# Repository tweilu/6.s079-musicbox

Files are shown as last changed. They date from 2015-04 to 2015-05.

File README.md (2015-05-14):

# 6.s079-musicbox
Final project for 6.S079 Computational Fabrication.

Final Report: Documentation/6.S079FinalReport.pdf

Web application: https://tweilu.scripts.mit.edu/musicbox/

Directory Structure

- CAD/ contains the CAD files for the static music box parts
- Code/
  - Cylinder/ contains the OpenSCAD and OpenJsCad scripts for cylinder generation and some example cylinders
  - Comb/ contains the original Python script and the ported OpenJsCad script for comb generation and some example combs
  - MIDI-Parser/ contains the standalone MIDI parser code
- Documentation/ contains all the reports and presentations from class
- Examples/ contains example MIDI files
- webapp/ contains the source code for the web application, which combines the MIDI parser with the cylinder and comb scripts

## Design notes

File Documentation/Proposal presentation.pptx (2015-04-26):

## Music boxes from MIDI

Wei-Wei Lu, Trevor Walker

## Problem and Motivation

- Inspired by project idea shown in class
  - Custom music boxes traditionally costly
- Manual note and scale input is tedious
  - MIDI encodes all necessary information
- Plastic comb sounds bad
  - Computational fabrication techniques work with other materials too

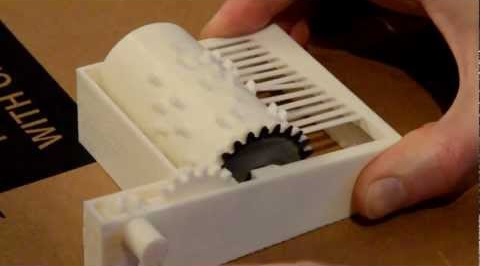
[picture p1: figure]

## Background and Tools

- Major music box parts and their functions
  - Cylinder (notes/timing)
  - Comb (scale)
  - Clockwork mechanism (tempo)
- OpenSCAD
  - Parametric description of part → printable STL
  - Applying skills learned from assignment 2

## Technical Method: Generation

- Front end: JavaScript web app
  - User access is easy
  - No external libraries or installation required
- Back end: OpenJSCAD
  - JavaScript wrapper for OpenSCAD
  - JS code determines low-level parameters, then passes them to SCAD routine
- User parameters
  - Which MIDI track to use
  - Which portion of song to encode on cylinder

## Technical Method: Fabrication

- Cylinder and mechanism: 3D printed ABS/PLA
  - Feasibility already shown
  - Gears and mechanisms are common
- Comb: Laser cut stainless steel
  - Sounds much better than plastic
  - Very thin metal is possible to laser cut
  - Dimensions can be matched to known acoustic properties of alloy

## Expected results

- Web app for generating printable files
  - Only necessary parameters exposed
  - Produces downloadable STL/OBJ for printing and SVG/DXF for laser cutting
- Functional music boxes
  - Demonstrated during final presentation

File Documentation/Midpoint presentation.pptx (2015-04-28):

## Midpoint: MIDI music boxes

Wei-Wei Lu, Trevor Walker

## Project recap

- 3D printing custom music boxes
- Interactive design based on MIDI
- Improves on existing solutions
  - Easier to design
  - Better sound


## Project components

- 3D-printable music box, without cylinder
- MIDI parser producing OpenSCAD files for cylinder
- Python script generating comb to correspond with cylinder
- Web app for interactive generation of comb and cylinder from MIDI

## Progress so far

- Complete

- Base music box
- MIDI → cylinder conversion
- Automatic comb generation

- In progress

- Web interface

## Example cylinder

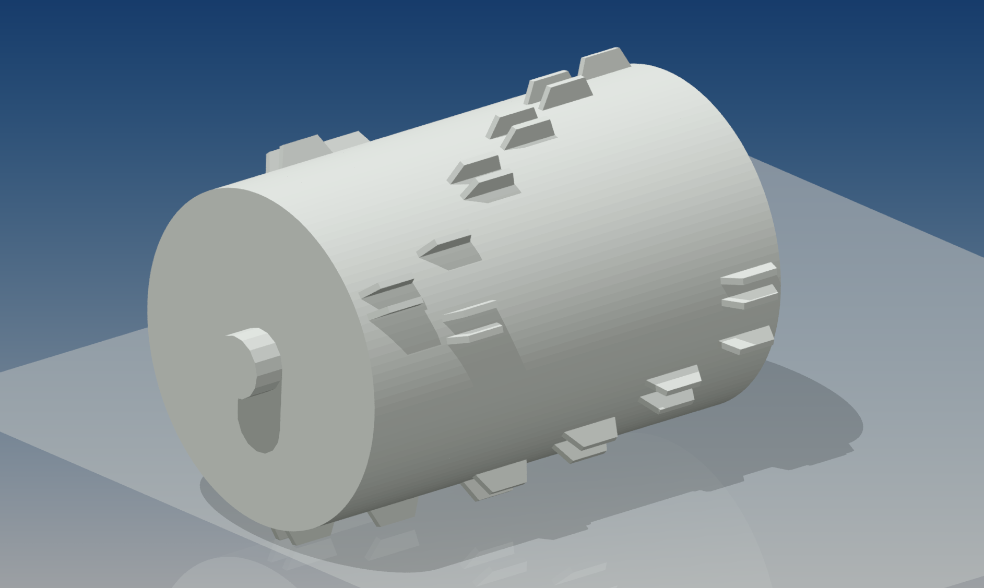
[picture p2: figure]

## Music box frame

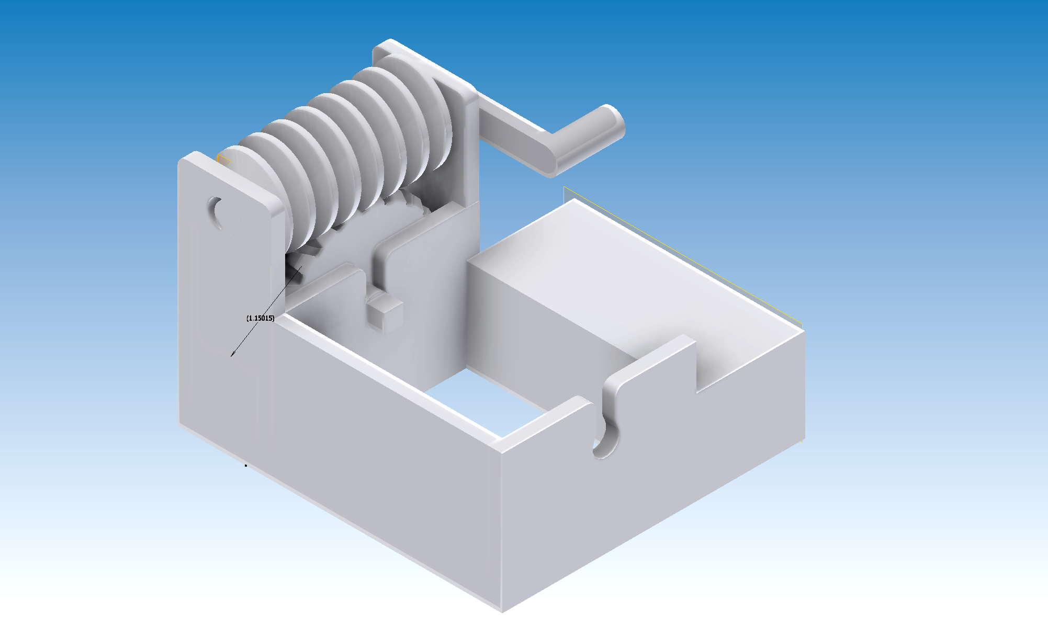
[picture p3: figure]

## Example comb

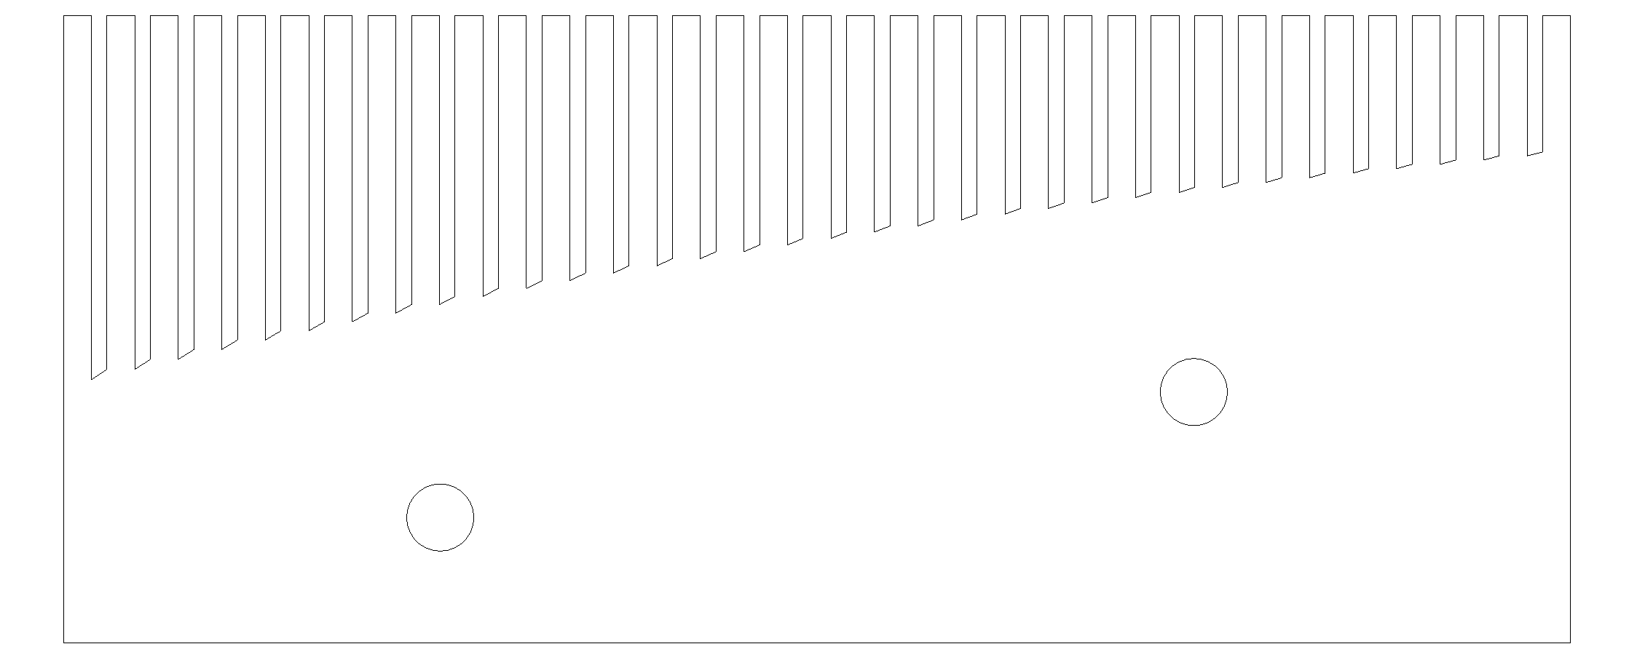
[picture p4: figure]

## What’s left

- Finish web app
- Prototype
  - Test whether fabricated design meets expectations
- Iterate
  - Improve anything not up to spec

## Questions?

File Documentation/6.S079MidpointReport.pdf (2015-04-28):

Music Box Generation from MIDIs 6.S079 Midpoint Project Report Trevor Walker and Tiffany Lu

Motivation

The problem we are tackling with our final project is allowing users to generate custom music boxes by simply uploading a MIDI music file containing the melody. The key goals in this task are to decrease the cost to the user of creating a custom music box and to make it easier to generate boxes by allowing a user to upload the desired song instead of having to manually input each note and the rhythms while still maintaining good sound quality. The custom 3D-printed music box was suggested in class; however, inputting the song for the music box is very clunky, and the fully 3D-printed box does not sound very good due to the plastic’s thin sound, so we plan to integrate a steel comb in order to make the custom boxes sound like traditional music boxes.

Technical Approach

In order to generate the custom music boxes, we will build a node.js web application that allows the user to upload a MIDI file and will output the .STL and .DXF for 3D printing and laser cutting. There are four main components to this: the JavaScript MIDI parser, the cylinder generation, the comb generation, and the box generation. The web application will provide an interface that allows users to upload a file and then subsequently view and download the resulting files.

MIDI Parser
The role of the JavaScript MIDI parser is to extract the relevant note and timing data from the MIDI file to pass to both the cylinder and comb modules. The web application provides an input field for the user to upload a file, and once chosen, it is read as a binary string and fed into a JavaScript MIDI parser called jasmid (https://github.com/gasman/jasmid). The parser surfaces a “header” portion of the MIDI file, which contains the MIDI format, number of tracks, and the timing interval, as well as a “tracks” portion of the file, which contains the actual note data. The “tracks” property contains a list of events for each track. We use only the MIDI “note on” event to signify when a note should be played, ignoring the “note off” event because a music box cannot sustain notes.

To generate the comb, we require all unique notes that are played through the whole song, so we iterate through the “note on” events to gather the unique MIDI note numbers. To generate the cylinder, we require [combtooth number, timing] pairs. We use the list of unique notes to get the combpin numbers, and to get the timing, each event also has a deltatime property, which indicates the time between the current event and the last, so we build the [combtooth number, timing] pairs by accumulating those differences. These two arrays are passed on to their respective modules.

Comb
The comb component is a Python script that takes in the list of unique notes in the song in the MIDI note number format and outputs a .DXF file for laser cutting. The lengths of the teeth on the comb are calculated by taking the MIDI note numbers and converting them to frequency, and using the following equation to calculate the length:

L = √
0.162 f

a√d

Y

where a is thickness, f is frequency, Y is the Young’s modulus, d is density, and L is the length. For the stainless steel we intend to cut the comb out of, the constants are:
a = 0.36 in
d = 0.289 lbs/in

3
Y = 2.85 x 10

7 ksi

The output .DXF is created using the ezdxfPython library.

Cylinder
The cylinder component is an OpenJSCAD routine, which takes in the [combtooth, timing] pairs as described above and generates a 3D-printable cylinder (.STL) with pins in the corresponding locations. The spacing between the pins both along and around the cylinder is variable and depends on the length of the song and the number of unique notes the song contains.

We calculate the spacing of the pins around the cylinder using the length of the song and the circumference of the cylinder, and we calculate the spacing of the pins along the cylinder using the number of unique notes the song contains. To place the pins on the cylinder, we iterate through the array of pairs and calculate the angle offsets depending on the timing.

Music Box
The box component is designed statically as a CAD file, which provides slots to insert the cylinder and comb. The box uses a worm drive attached to a crank to turn the cylinder.

Progress & Current Results

Currently, each of the separate components as described above are implemented, but they have not yet been integrated with each other. The MIDI parser is currently a static HTML page that takes in a useruploaded file and outputs the relevant data to the console.

The comb Python script takes in a list of notes to put on the comb and outputs a .DXF file as seen below.

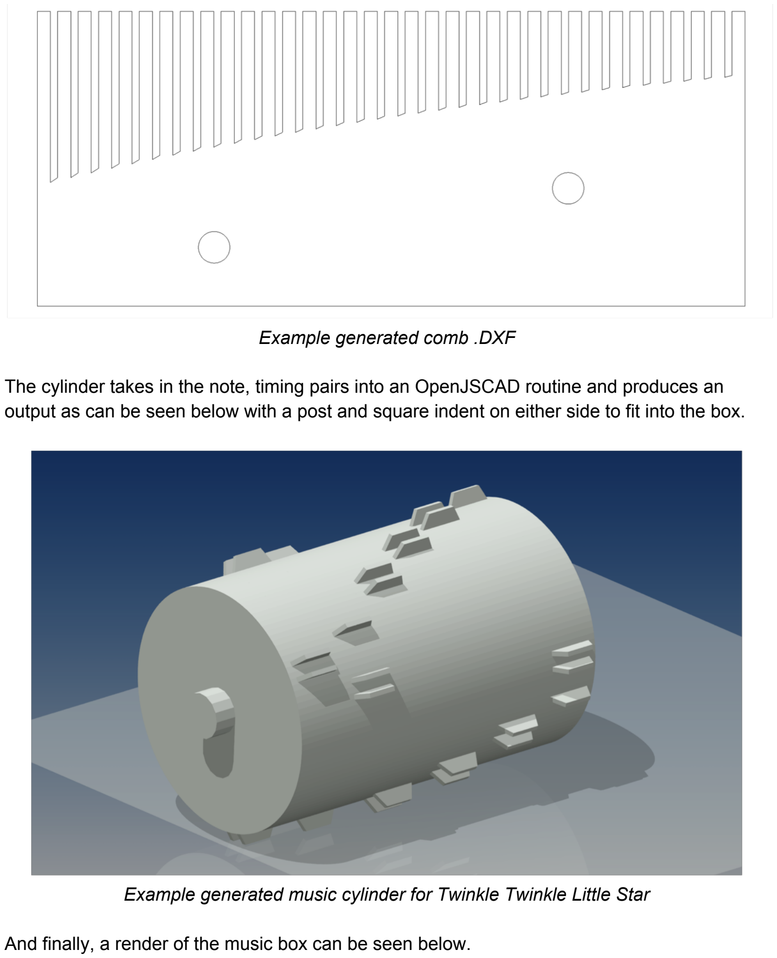
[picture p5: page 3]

Example generated comb .DXF

The cylinder takes in the note, timing pairs into an OpenJSCAD routine and produces an output as can be seen below with a post and square indent on either side to fit into the box.

Example generated music cylinder for Twinkle Twinkle Little Star

And finally, a render of the music box can be seen below.

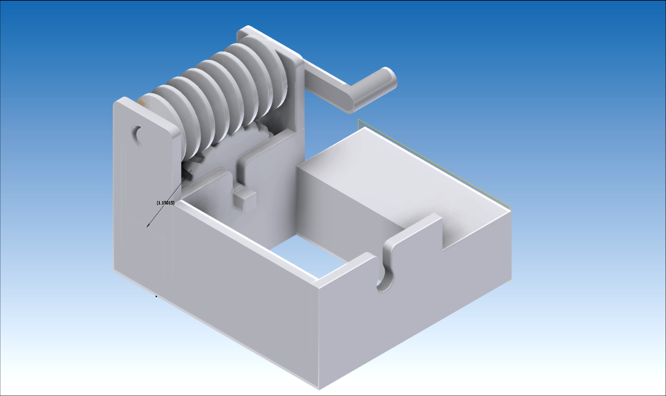
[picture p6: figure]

Music box render

Next Steps & Expected Results

The next steps for this project are to connect all of the four components together into the final web application. We also need to print and laser cut the generated objects to ensure they work together and make adjustments as needed. We plan to evaluate the laser cut comb by comparing the output frequencies with the desired ones, and we will compare the sound quality and overall function of the music box with both real and fully 3D printed ones.

We expect our final product to allow the user to upload a MIDI file and be able to download their corresponding .STL and .DXF files in the same interface. We also expect to have a few printed music boxes, generated by our system.

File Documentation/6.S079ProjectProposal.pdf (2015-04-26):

Music Box Generation from MIDIs 6.S079 Project Proposal
Trevor Walker and Tiffany Lu

Problem and Motivation
The problem we wish to tackle with our final project is allowing users to generate custom music boxes by simply uploading a MIDI music file containing the melody. Our overall goals are to decrease the cost to the user of creating a custom music box and to make it easier to generate boxes by allowing a user to upload the desired song instead of having to manually input each note and the rhythms while still maintaining good sound quality. The custom 3D-printed music box was suggested in class; however, the fully 3D-printed music box does not sound very good due to the plastic’s thin sound, so we wish to integrate a steel comb in order to make the custom boxes sound like traditional music boxes.

Background and Tools
Music boxes have been around since the 18th century, and their core design has not changed much. In order to generate these boxes, we must understand both how the boxes are designed as well as the music theory. A simple handcranked music box is made up of four parts: the bed plate, which is the foundation that holds the whole mechanism, the cylinder, which has pins that pluck the notes, the comb, which the pins on the cylinder pluck to produce sound, and the ratchet lever, which the user turns to play the song.

We will generate the 3D-printed parts with OpenSCAD, applying the skills learned from assignment 2.

Proposed Technical Method
There are two components to our technical method: computational generation and fabrication of the music boxes. The generation component will take the form of a web application, written in Javascript, that will take in the two parameters from the user, the MIDI file and the portion of the song they wish to encode, and it will output the OBJ or STL file for the music box and an SVG or DXF for laser cutting the comb. We will parse the notes from the MIDI file and use them as input to the generation code, using the OpenJSCAD library (http://openjscad.org/) to generate the model. The fabrication component involves actually creating the physical music box. We will 3D print the bed plate, cylinder, and lever in ABS or PLA, and we will laser cut the comb in thin stainless steel.

Expected Results
The finished project should consist of a web application that allows users to generate their own custom music boxes, and we hope to create and assemble a few music boxes of our own using the web app, for demonstration.

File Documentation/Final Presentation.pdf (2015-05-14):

# Making MIDI Real: Parametric Music Boxes

Wei-Wei Lu, Trevor Walker

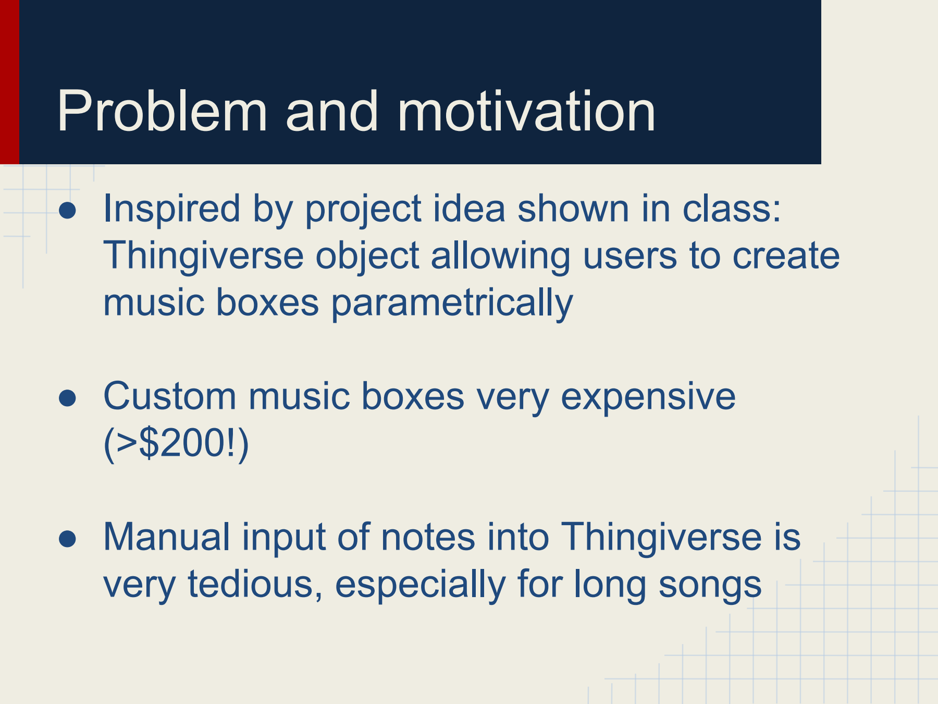
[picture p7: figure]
music boxes parametrically; ● Custom music boxes very expensive (>$200!); very tedious, especially for long songs; Problem and motivation

### - Inspired by project idea shown in class: Thingiverse object allowing users to create

### - Manual input of notes into Thingiverse is

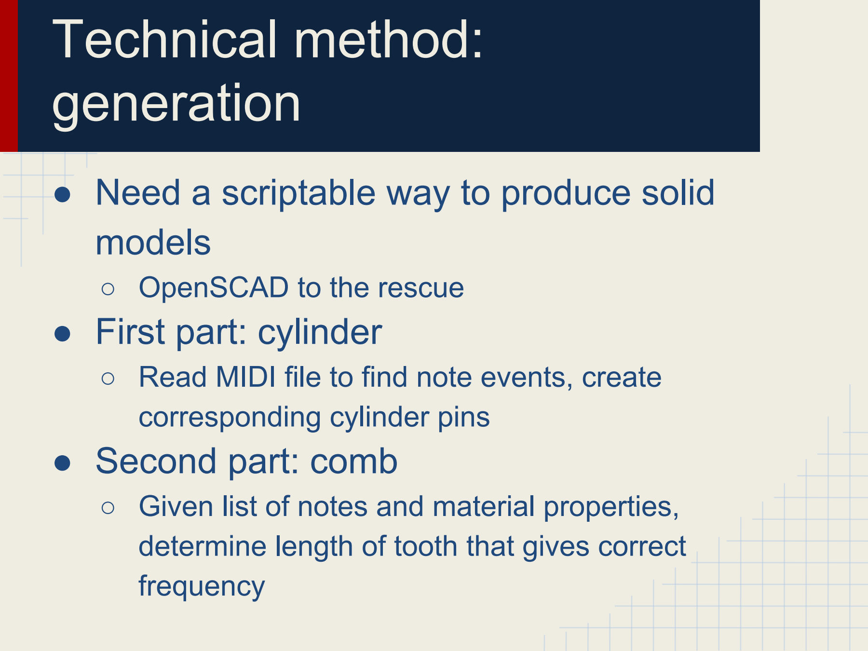
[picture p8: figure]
Technical method: generation; models; ○ OpenSCAD to the rescue ● First part: cylinder; corresponding cylinder pins ● Second part: comb; frequency

### - Need a scriptable way to produce solid

- Read MIDI file to find note events, create
- Given list of notes and material properties, determine length of tooth that gives correct

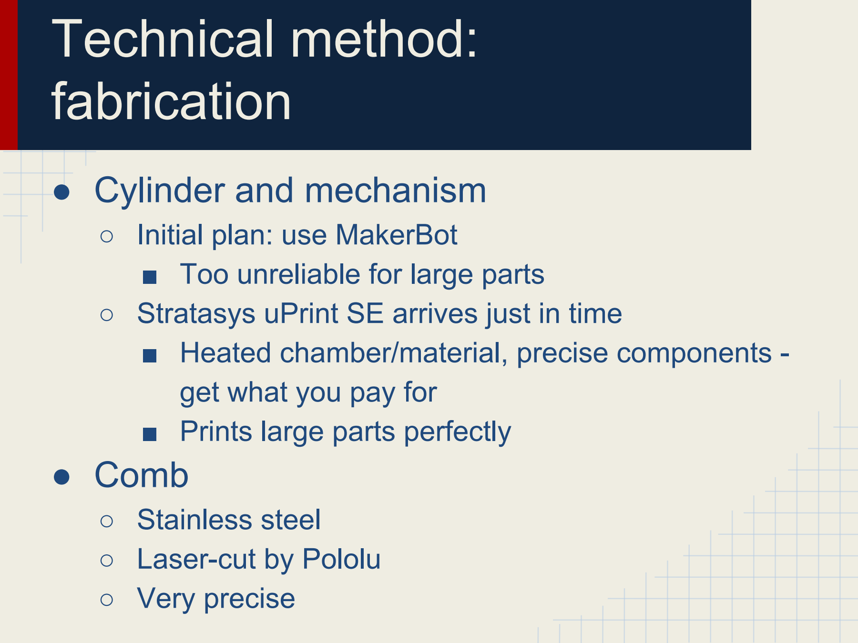
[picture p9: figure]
Technical method: fabrication; ● Cylinder and mechanism; ○ Initial plan: use MakerBot ■ Too unreliable for large parts; get what you pay for ■ Prints large parts perfectly ● Comb; ○ Stainless steel ○ Laser-cut by Pololu ○ Very precise

- Stratasys uPrint SE arrives just in time
■ Heated chamber/material, precise components -

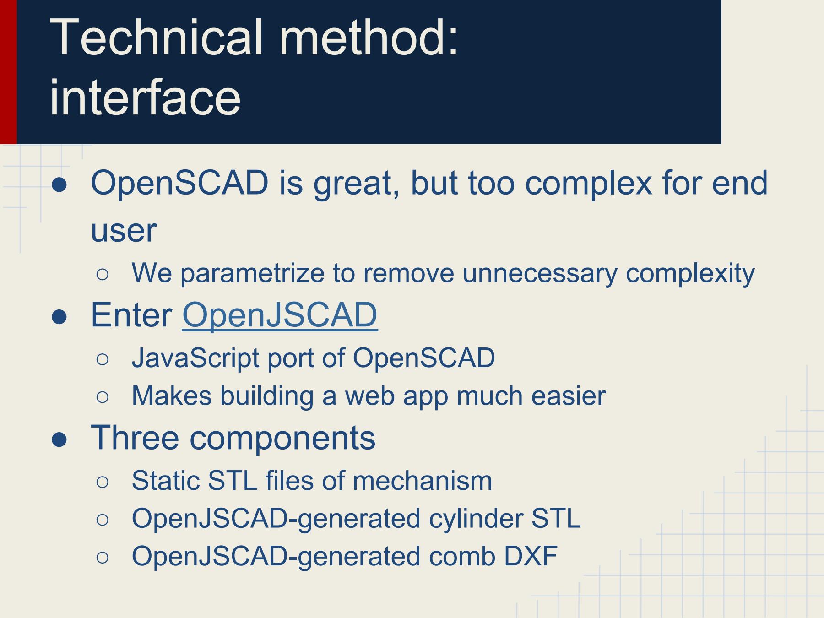
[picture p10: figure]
Technical method: interface; user; ● Enter OpenJSCAD; ○ JavaScript port of OpenSCAD ○ Makes building a web app much easier ● Three components; ○ Static STL files of mechanism ○ OpenJSCAD-generated cylinder STL ○ OpenJSCAD-generated comb DXF

### - OpenSCAD is great, but too complex for end

- We parametrize to remove unnecessary complexity

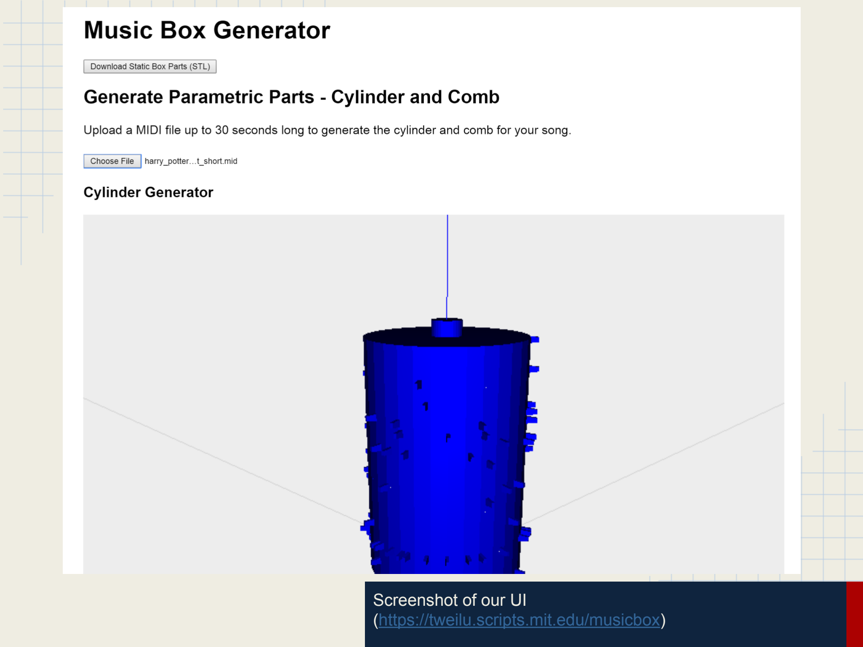
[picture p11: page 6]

Screenshot of our UI
(https://tweilu.scripts.mit.edu/musicbox)

# Results: photographic evidence

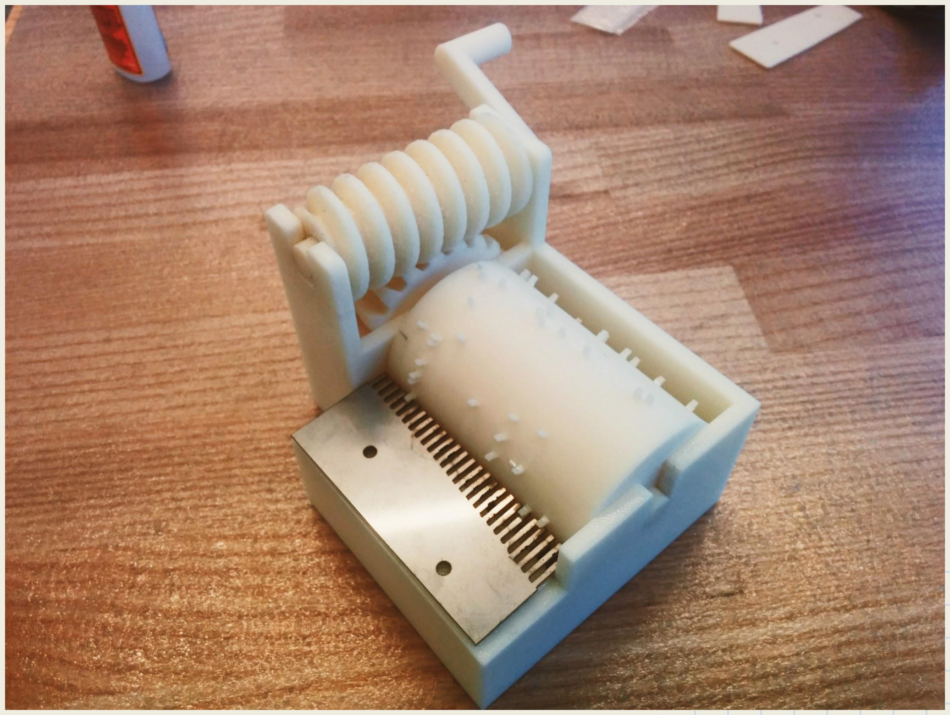
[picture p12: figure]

# Results: live demonstration

# Results: experimental data

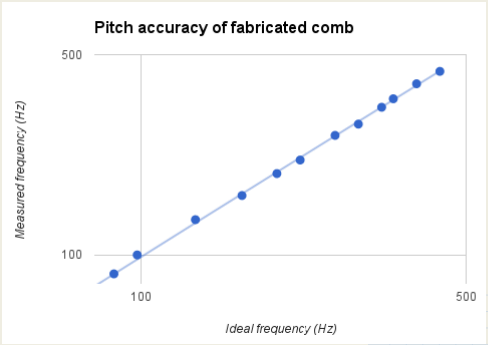
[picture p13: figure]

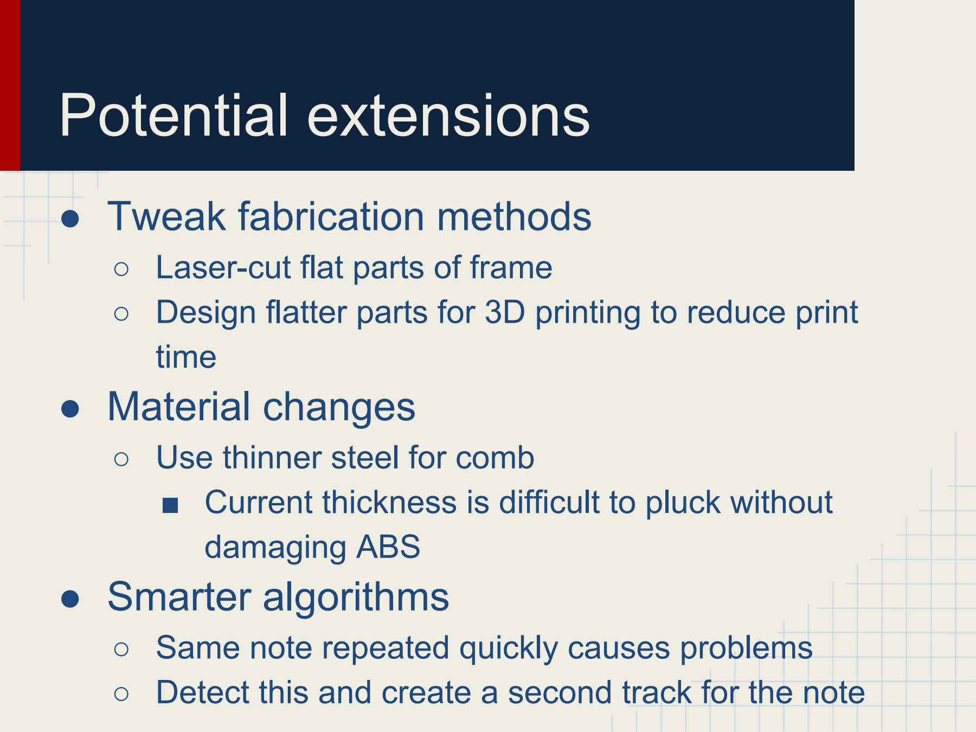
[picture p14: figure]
Potential extensions; ● Tweak fabrication methods; ○ Laser-cut flat parts of frame; time ● Material changes; ○ Use thinner steel for comb; damaging ABS ● Smarter algorithms

- Design flatter parts for 3D printing to reduce print

■ Current thickness is difficult to pluck without

- Same note repeated quickly causes problems
- Detect this and create a second track for the note

# Questions?

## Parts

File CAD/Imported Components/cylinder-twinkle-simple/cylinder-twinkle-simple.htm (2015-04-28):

Autodesk Inventor Translation Report | Tuesday, April 28, 2015 ( 12:26 PM)
Source File: | C:\Users\Trevor\Google Drive\Classwork\6.S079\Project\6.s079-musicbox\Code\Cylinder\cylinder-twinkle-simple.stl
Translator Type: | STL | Sending System:
Author: |  | Translation Time: | 00:00:00
Options
Import Type: | N/A
Entity Types to Import: | Meshes
Import into Repair Environment: | N/A
Import Assembly as Single Part: | N/A
Create Surfaces As: | N/A
Check Parts during Load: | N/A
Auto Stitch: | N/A
Enable Advanced Healing: | N/A
Color Red/Green/Blue Order: | RGB
+/- | Name | Inventor File | Status
[ ] | cylinder-twinkle-simple.ipt | C:\Users\Trevor\Google Drive\Classwork\6.S079\Project\6.s079-musicbox\CAD\Imported Components\cylinder-twinkle-simple\cylinder-twinkle-simple.ipt | Successful

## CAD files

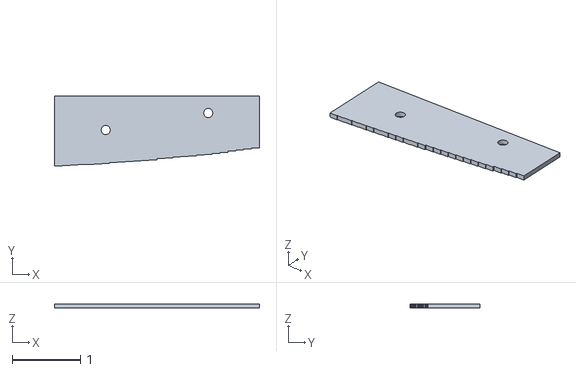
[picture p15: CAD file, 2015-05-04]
CAD/Bases/harry_potter_base.stl
3.00 x 1.03 x 0.0625

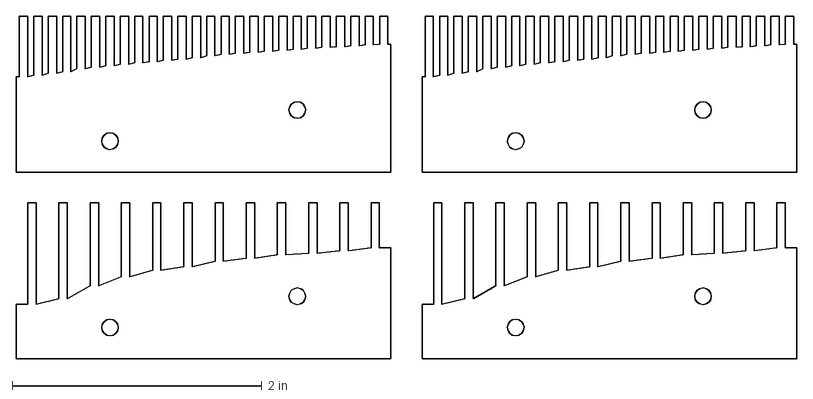
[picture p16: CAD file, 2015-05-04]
CAD/Combs.dxf
6.25 x 2.74 in

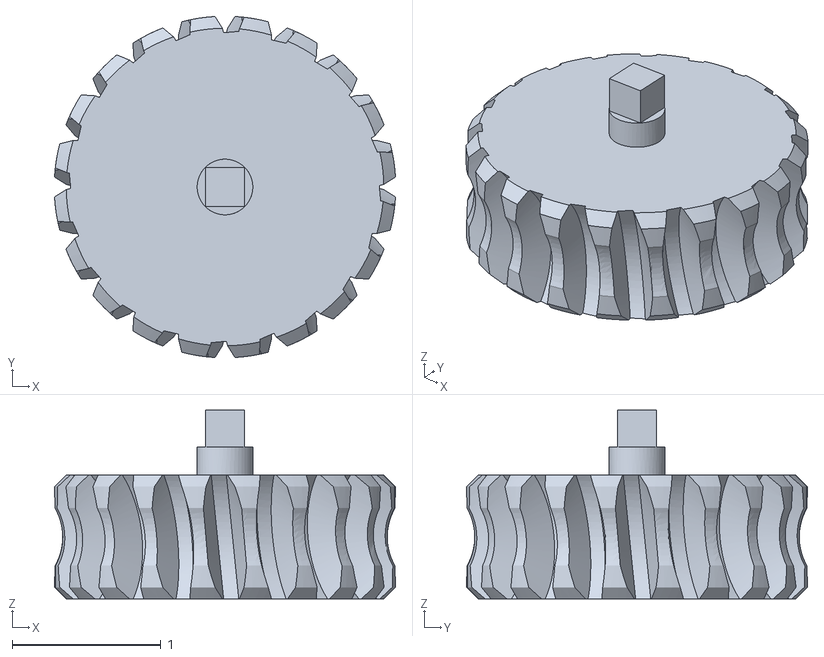
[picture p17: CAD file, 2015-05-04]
CAD/STL/Worm Gear.stl
2.30 x 2.30 x 1.27

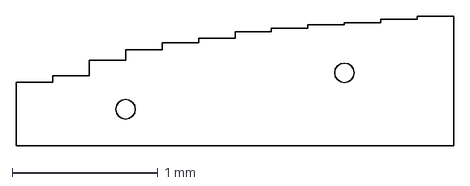
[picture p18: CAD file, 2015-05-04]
Code/Comb/twinkle_twinkle_base.dxf
3.00 x 0.887 mm

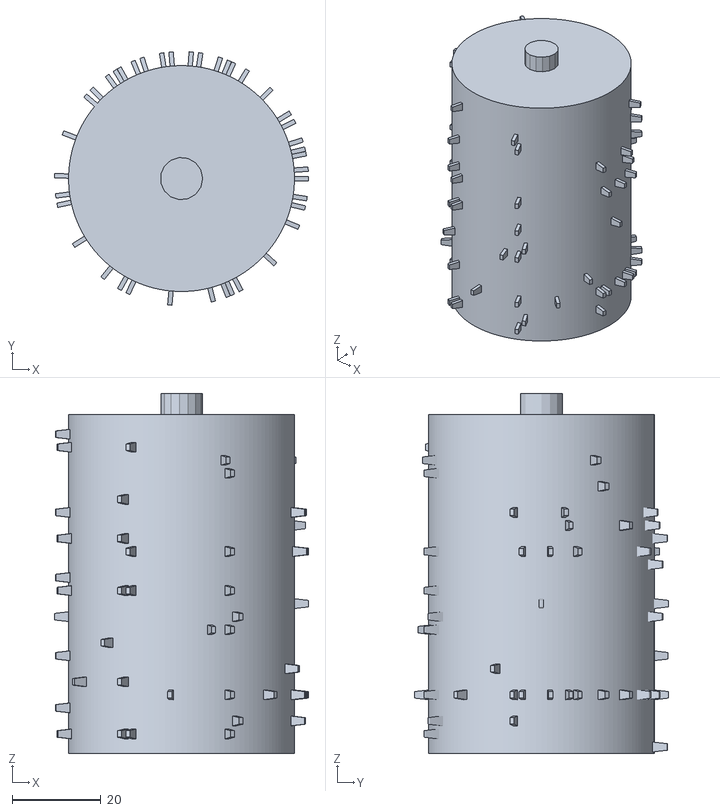
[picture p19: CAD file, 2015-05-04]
Code/Cylinder/harrypotter-short.stl
57.2 x 57.0 x 81.0

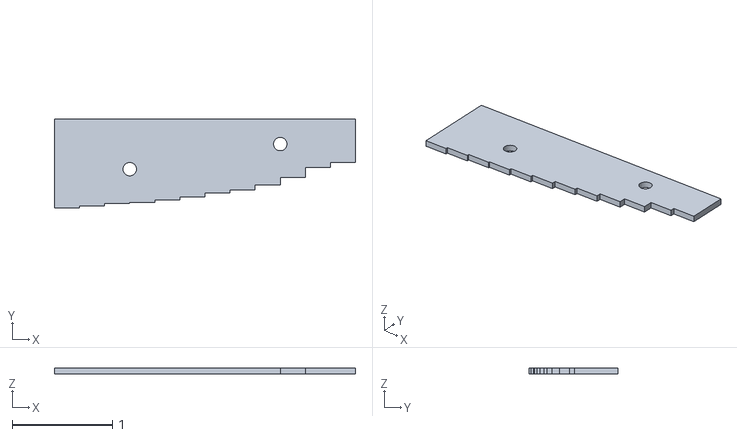
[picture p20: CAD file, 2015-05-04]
CAD/Bases/twinkle_twinkle_base.stl
3.00 x 0.887 x 0.0625

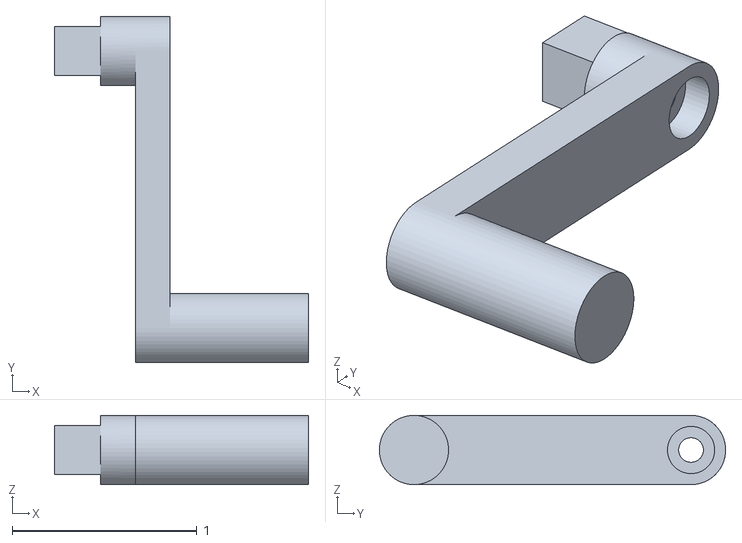
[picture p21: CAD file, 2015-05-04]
CAD/STL/Crank.stl
1.38 x 1.87 x 0.375

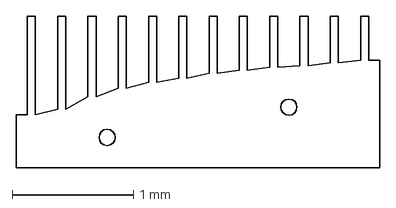
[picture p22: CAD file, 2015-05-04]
Code/Comb/twinkle_twinkle_comb.dxf
3.00 x 1.25 mm

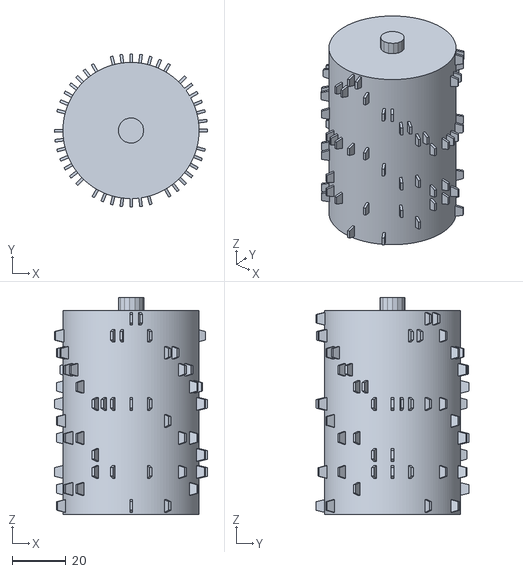
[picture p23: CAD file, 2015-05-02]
Code/Cylinder/twinkletwinkle.stl
57.2 x 57.2 x 81.0

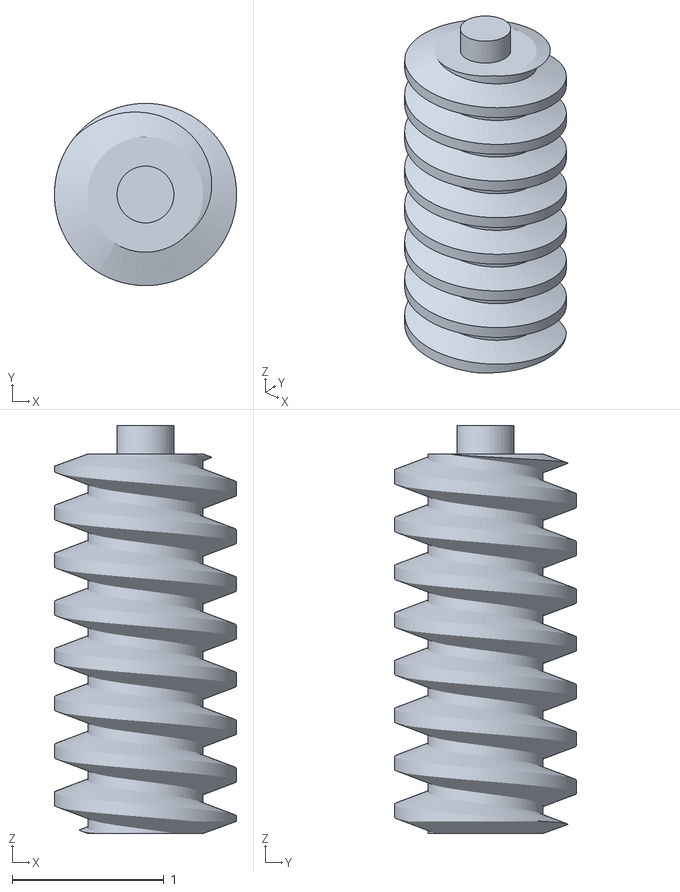
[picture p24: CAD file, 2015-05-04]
CAD/STL/Worm.stl
1.20 x 1.20 x 2.69

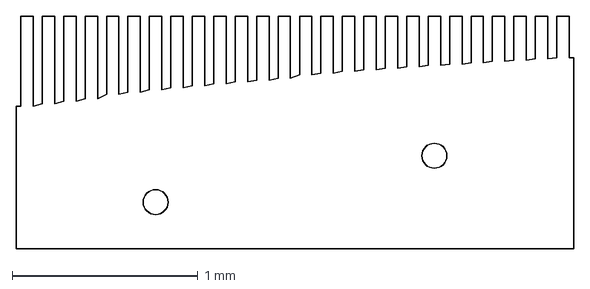
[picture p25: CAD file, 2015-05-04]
Code/Comb/harry_potter_comb.dxf
3.00 x 1.25 mm

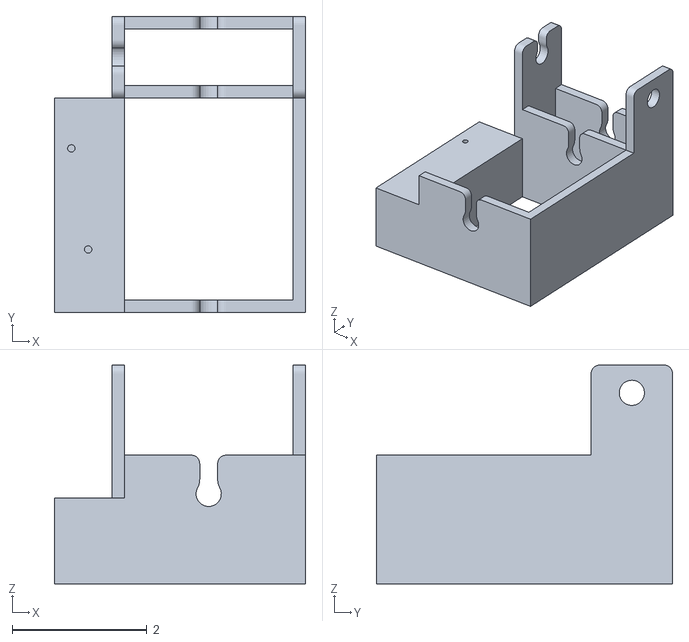
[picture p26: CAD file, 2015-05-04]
CAD/STL/Box.stl
3.73 x 4.40 x 3.25

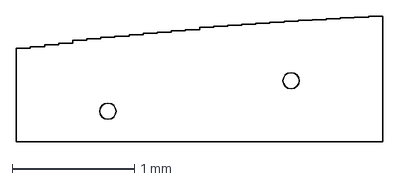
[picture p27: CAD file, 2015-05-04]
Code/Comb/harry_potter_base.dxf
3.00 x 1.03 mm

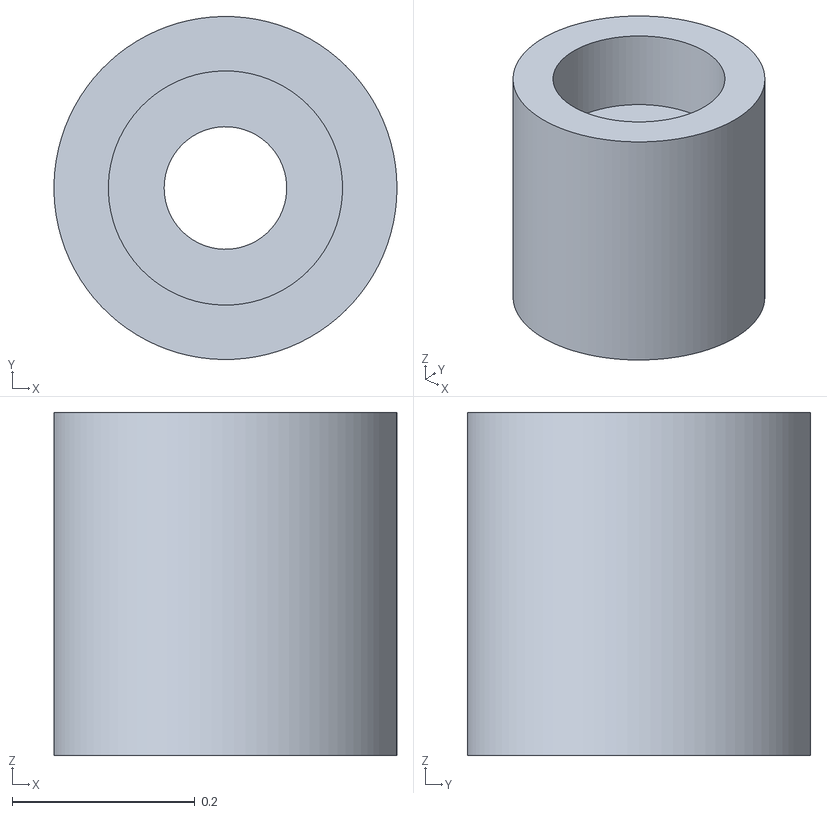
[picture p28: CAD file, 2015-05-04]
CAD/STL/axle.stl
0.375 x 0.375 x 0.375

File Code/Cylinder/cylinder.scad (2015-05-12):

// cylinder params
radius = 25.4; //1 inch radius
height = 76.2; //3 inch height

// [comb-pin number, time]
// twinkle twinkle notes
notes = [[6,0],[3,0],[2,0],[6,12],[10,24],[6,24],[2,24],[10,36],[11,48],[6,48],[0,48],[11,60],[10,72],[6,72],[2,72],[9,97],[5,97],[0,97],[9,109],[8,121],[4,121],[2,121],[8,133],[7,145],[4,145],[1,145],[7,157],[6,169],[3,169],[2,169],[10,194],[6,194],[2,194],[10,206],[9,218],[5,218],[0,218],[9,230],[8,242],[4,242],[1,242],[8,254],[7,266],[4,266],[1,266],[10,291],[6,291],[2,291],[10,303],[9,315],[5,315],[0,315],[9,327],[8,339],[4,339],[1,339],[8,351],[7,363],[4,363],[1,363],[6,388],[3,388],[2,388],[6,400],[10,412],[6,412],[2,412],[10,424],[11,436],[6,436],[0,436],[11,448],[10,460],[6,460],[2,460],[9,485],[5,485],[0,485],[9,497],[8,509],[4,509],[2,509],[8,521],[7,533],[4,533],[1,533],[7,545],[6,557],[3,557],[2,557]];
// number of ticks
songlength = 557+24;
numnotes = 12.0;

// harry potter notes
//notes = [[11,0],[4,22],[15,22],[18,58],[4,69],[17,69],[4,91],[15,91],[22,138],[4,160],[20,160],[4,231],[17,231],[4,302],[15,302],[18,338],[4,349],[17,349],[10,371],[14,371],[0,418],[16,418],[4,440],[11,440],[7,487],[11,509],[0,556],[4,578],[15,578],[18,614],[4,625],[17,625],[4,647],[15,647],[22,694],[3,716],[13,716],[18,716],[25,716],[7,817],[10,919],[3,966],[7,966],[13,966],[18,966],[24,966],[1,988],[12,988],[16,988],[23,988],[5,1089],[8,1191],[1,1238],[5,1238],[12,1238],[16,1238],[19,1238],[1,1260],[12,1260],[15,1260],[23,1260],[4,1361],[9,1463],[22,1499],[1,1510],[4,1510],[9,1510],[12,1510],[15,1510],[21,1510],[2,1532],[10,1532],[4,1633],[6,1735],[2,1782],[4,1782],[18,1782],[4,1804],[15,1804]];
// number of ticks
//songlength = 1804+47;
// number of comb teeth
//numnotes = 26.0;

// one measure spacing
hspacing = 2*PI*radius/songlength;
// comb-pin spacing
vspacing = height/numnotes;

module makeCylinder() {
    union() {
        cylinder(h = height, r = radius, $fn=256);
        for (i = [0:len(notes)-1]) {
            pinnum = notes[i][0];
            time = notes[i][1];
            angle = hspacing*time/radius*180/PI;
            x = cos(angle)*radius;
            y = sin(angle)*radius;
            translate([x,y,0]) {
                translate([0,0,vspacing/2+pinnum*vspacing]) rotate([0,0,angle]) pin();
            }
        }
    }
}

module pin() {
    rotate([90,90,0]) trapezoid(vspacing, vspacing*0.5,6.35,1);
}

module trapezoid(width_base, width_top,height,thickness) {
  translate([0,0,-thickness/2]) linear_extrude(height = thickness) polygon(points=[[-width_base/2,-height/2],[width_base/2,-height/2],[width_base/2-(width_base-width_top)/2,height/2],[-width_base/2+(width_base-width_top)/2,height/2]], paths=[[0,1,2,3]]);
}

module completeCylinder() {
    union() {
        difference() {
            makeCylinder();
            cube(size=[6.73519,6.73519,12.7], center=true);
        }
        $fn=64;
        translate([0,0,height]) cylinder(h=4.7625,r=4.7625);
    }
}

completeCylinder();
//translate([radius+5,0,0]) cylinder(h=height,r=1);

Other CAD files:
Code/Cylinder/harrypotter.stl
Code/Comb/dynspace_base.dxf
Code/Comb/comb.dxf
Code/Comb/dynspace_comb.dxf
CAD/Assembly.iam
CAD/Assembly/Design Accelerator/OldVersions/Worm Gear1.0011.ipt
CAD/Assembly/Design Accelerator/OldVersions/Worm Gears1.0008.iam
CAD/Assembly/Design Accelerator/OldVersions/Worm1.0012.ipt
CAD/Assembly/Design Accelerator/Worm Gear1.ipt
CAD/Assembly/Design Accelerator/Worm Gears1.iam
CAD/Assembly/Design Accelerator/Worm1.ipt
CAD/Bases/OldVersions/harry_potter_base.0001.ipt
CAD/Bases/OldVersions/twinkle_twinkle_base.0001.ipt
CAD/Bases/harry_potter_base.ipt
CAD/Bases/twinkle_twinkle_base.ipt
CAD/Box.ipt
CAD/Combs.dwg
CAD/Crank.ipt
CAD/Imported Components/cylinder-twinkle-simple/cylinder-twinkle-simple.ipt
CAD/OldVersions/Assembly.0022.iam
CAD/OldVersions/Box.0021.ipt
CAD/OldVersions/Crank.0008.ipt
CAD/OldVersions/axle.0004.ipt
CAD/axle.ipt
Code/Comb/base.dxf

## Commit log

2015-04-26 Added python code to generate combs/plastic bases (works), added beginnings of CAD for the static part of the music box.
    [Assembly.0002.iam, Assembly.iam, Worm Gear1.0001.ipt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]
2015-04-27 Basic cylinder given a list of notes.
    [cylinder.scad]
2015-04-27 cylinder update to use whole length and to use time not length of notes
    [cylinder.scad]
2015-04-28 cylinder a bit better
    [cylinder.scad]
2015-04-28 added jasmid files to parse .mid
    [cylinder-twinkle-simple.stl, cylinder.scad]
2015-04-28 made more progress on CAD
    [Assembly.0002.iam, Assembly.0005.iam, Assembly.iam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]
2015-04-28 Fix cylinder dimensions and add post/square indent
    [cylinder-twinkle-simple.stl, cylinder.scad]
2015-04-28 Added midpoint presentation, continued CAD work on music box
    [Assembly.0005.iam, Assembly.0010.iam, Assembly.iam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]
2015-04-30 Finished CAD (STL export pending), updated script to keep tine width constant
    [Assembly.0010.iam, Assembly.0022.iam, Assembly.iam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]
2015-05-02 Twinkle Twinkle and Harry Potter cylinders for printing
    [cylinder-twinkle-simple.stl, cylinder.scad, harrypotter.stl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]
2015-05-04 Updated comb code; generated sTL for all parts to be printed.
    [Box.stl, Combs.dwg, Combs.dxf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]
2015-05-04 shorter Harry Potter cylinder
    [cylinder.scad, harrypotter-short.stl]
2015-05-04 made cylinder smoother, compiled STLs
    [cylinder.scad, harry_potter_base.stl]
2015-05-05 all parts stl
    [all_parts.stl]
2015-05-12 update .jscad cylinder
    [cylinder.scad]
2015-05-12 Web app: upload a MIDI, download an .STL
2015-05-14 web app generates both comb and cylinder
2015-05-14 Add final report and presentation
    [all_parts.stl]
